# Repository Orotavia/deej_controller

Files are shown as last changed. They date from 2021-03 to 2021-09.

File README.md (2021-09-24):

# deej_controller

Custom controller for use with omriharel's [deej](https://github.com/omriharel/deej) software. Reads four rotary encoders with edge-driven interrupts to increment/decrement volume per channel. Volume data is sent over serial to the FT230X which appears as a serial port on the host PC. 

Known issues:
* FT230X and MCP1700 both output 3.3V onto the same rail. Need to separate to prevent voltage mis-match and resultant backwards current flow. 
* 5.3x10.2 SOIC16W footprints for SN74HC595N shift registers are too wide - Need to switch to SOIC16
* LED Bargraph footprints are too wide - Need to reduce row-to-row spacing, must likely by 2.54mm or some multiple

deej!

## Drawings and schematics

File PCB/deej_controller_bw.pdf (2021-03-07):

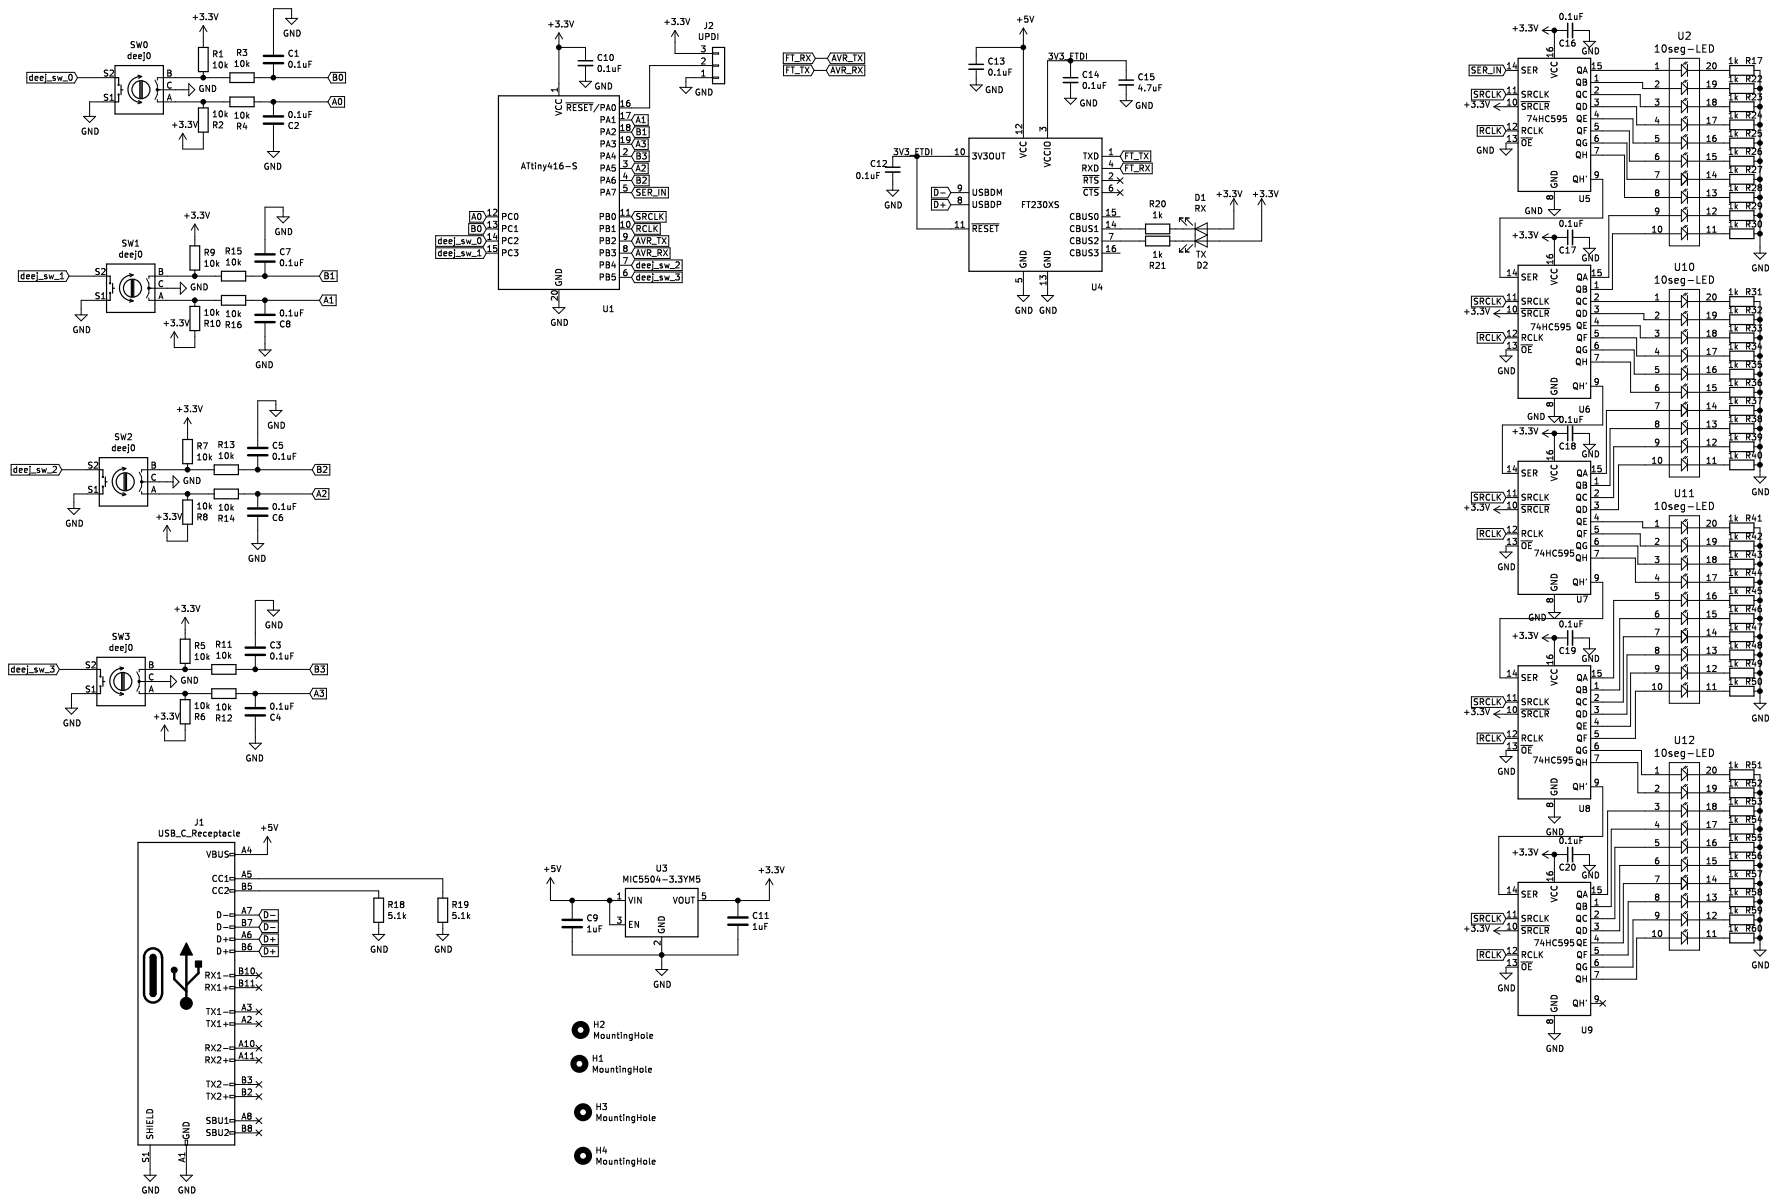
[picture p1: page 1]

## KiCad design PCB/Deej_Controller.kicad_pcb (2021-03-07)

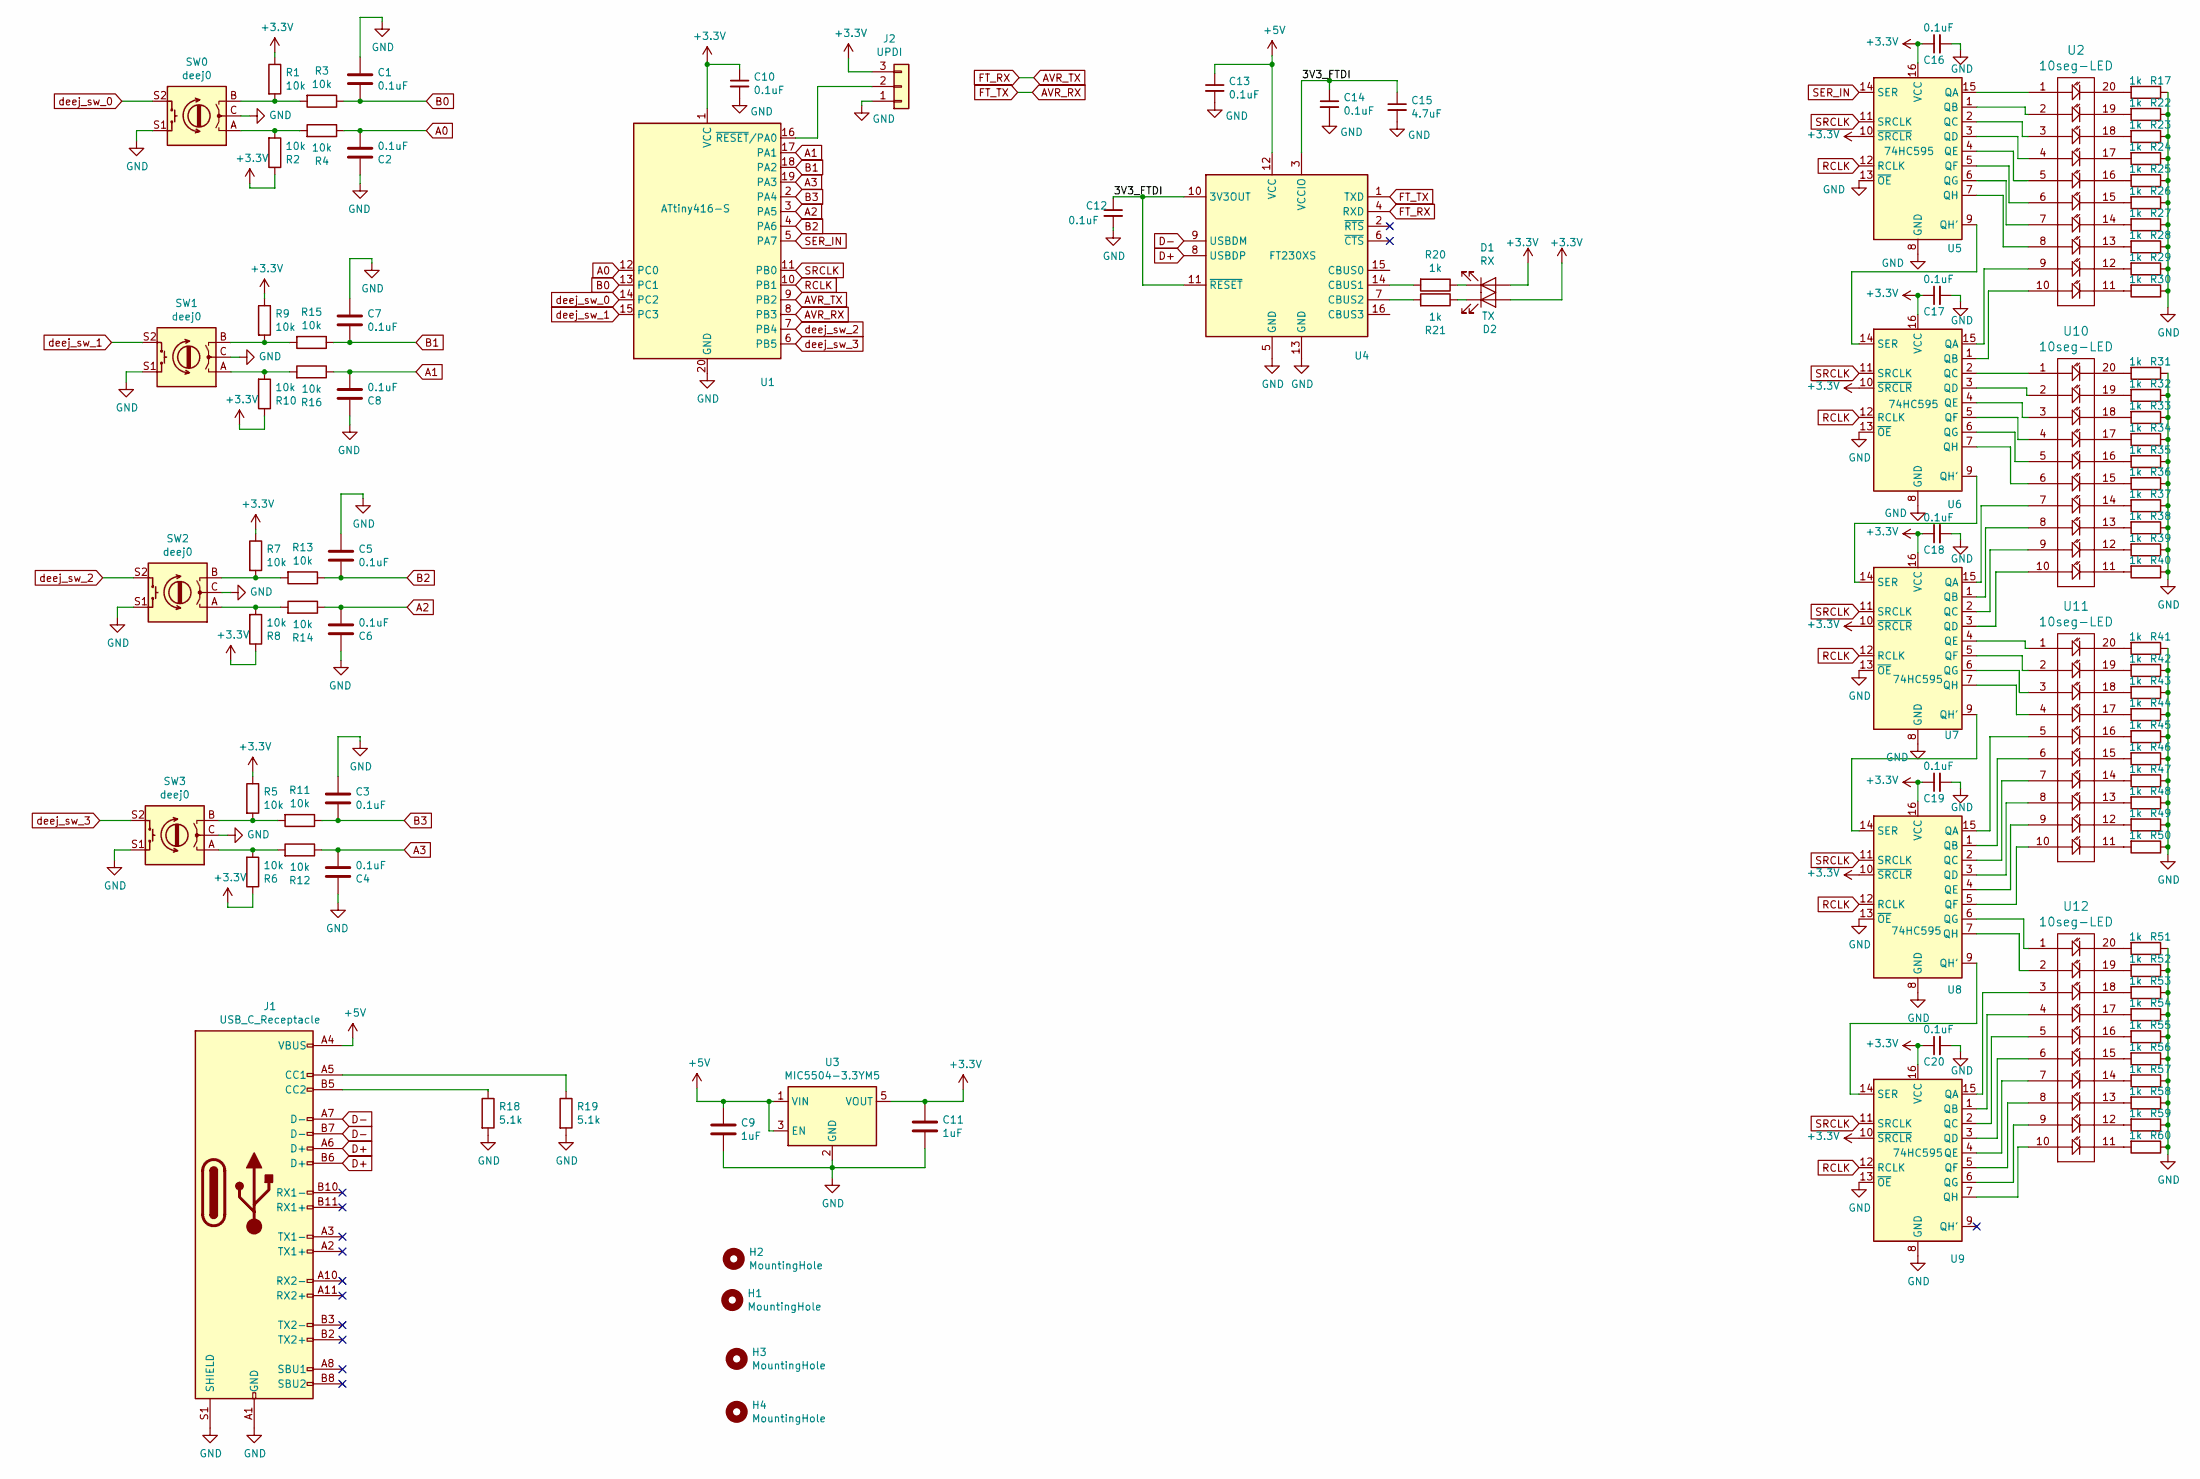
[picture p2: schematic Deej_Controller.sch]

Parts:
C1, C2, C3, C4, C5, C6, C7, C8, C10, C12, C13, C14, C16, C17, C18, C19, C20: 0.1uF; C_0603
C9, C11: 1uF; C_0603
C15: 4.7uF; C_0603
D1: RX; LED_0603
D2: TX; LED_0603
H1, H2, H3, H4: MountingHole; MountingHole_3.2mm_M3_DIN965_Pad
J1: USB_C_Receptacle; USB_C_GCT_ThruHole
J2: UPDI; UPDI_Header_2.54_smd
R1, R2, R3, R4, R5, R6, R7, R8, R9, R10, R11, R12, R13, R14, R15, R16: 10k; R_0603
R17, R20, R21, R22, R23, R24, R25, R26, R27, R28, R29, R30, R31, R32, R33, R34, R35, R36, R37, R38, R39, R40, R41, R42, R43, R44, R45, R46, R47, R48, R49, R50, R51, R52, R53, R54, R55, R56, R57, R58, R59, R60: 1k; R_0603
R18, R19: 5.1k; R_0603
SW0, SW1, SW2, SW3: deej0; PEC11R-Encoder
U1: ATtiny416-S; SOIC-20W_7.5x12.8mm_Pitch1.27mm
U2, U10, U11, U12: 10seg-LED; 10Segment_LED
U3: MIC5504-3.3YM5; SOT-23-5
U4: FT230XS; SSOP-16_3.9x4.9mm_Pitch0.635mm
U5, U6, U7, U8, U9: 74HC595; SOIC-16W_5.3x10.2mm_Pitch1.27mm

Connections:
+5V: C9.1, C13.1, J1.A4 (VBUS), J1.A9 (VBUS), J1.B4 (VBUS), J1.B9 (VBUS), U3.1 (VIN), U3.3 (EN), U4.12 (VCC)
A0: C2.1, R4.1, U1.12 (PC0)
A1: C8.1, R16.1, U1.17 (PA1)
A2: C6.1, R14.1, U1.3 (PA5)
A3: C4.1, R12.1, U1.19 (PA3)
AVR_RX: U1.8 (PB3), U4.1 (TXD)
AVR_TX: U1.9 (PB2), U4.4 (RXD)
B0: C1.1, R3.1, U1.13 (PC1)
B1: C7.1, R15.1, U1.18 (PA2)
B2: C5.1, R13.1, U1.4 (PA6)
B3: C3.1, R11.1, U1.2 (PA4)
D+: J1.A6 (D+), J1.B6 (D+), U4.8 (USBDP)
D-: J1.A7 (D-), J1.B7 (D-), U4.9 (USBDM)
GND: C1.2, C2.2, C3.2, C4.2, C5.2, C6.2, C7.2, C8.2, C9.2, C10.2, C11.2, C12.2, C13.2, C14.2, C15.2, C16.2, C17.2, C18.2, C19.2, C20.2, J1.A1 (GND), J1.A12 (GND), J1.B1 (GND), J1.B12 (GND), J1.S1 (SHIELD), J2.1, R17.1, R18.2, R19.2, R22.1, R23.1, R24.1, R25.1, R26.1, R27.1, R28.1, R29.1, R30.1, R31.1, R32.1, R33.1, R34.1, R35.1, R36.1, R37.1, R38.1, R39.1, R40.1, R41.1, R42.1, R43.1, R44.1, R45.1, R46.1, R47.1, R48.1, R49.1, R50.1, R51.1, R52.1, R53.1, R54.1, R55.1, R56.1, R57.1, R58.1, R59.1, R60.1, SW0.C, SW0.S1, SW1.C, SW1.S1, SW2.C, SW2.S1, SW3.C, SW3.S1, U1.20 (GND), U3.2 (GND), U4.5 (GND), U4.13 (GND), U5.8 (GND), U5.13 (~OE), U6.8 (GND), U6.13 (~OE), U7.8 (GND), U7.13 (~OE), U8.8 (GND), U8.13 (~OE), U9.8 (GND), U9.13 (~OE)
unnamed: D1.1 (K), R20.1
unnamed: D2.1 (K), R21.1
unnamed: J1.A5 (CC1), R19.1
unnamed: J1.B5 (CC2), R18.1
unnamed: J2.2, U1.16 (~RESET~/PA0)
unnamed: R1.2, R3.2, SW0.B
unnamed: R2.2, R4.2, SW0.A
unnamed: R10.2, R16.2, SW1.A
unnamed: R5.2, R11.2, SW3.B
unnamed: R6.2, R12.2, SW3.A
unnamed: R7.2, R13.2, SW2.B
unnamed: R8.2, R14.2, SW2.A
unnamed: R9.2, R15.2, SW1.B
unnamed: R17.2, U2.20
unnamed: R20.2, U4.14 (CBUS1)
unnamed: R21.2, U4.7 (CBUS2)
unnamed: R22.2, U2.19
unnamed: R23.2, U2.18
unnamed: R24.2, U2.17
unnamed: R25.2, U2.16
unnamed: R26.2, U2.15
unnamed: R27.2, U2.14
unnamed: R28.2, U2.13
unnamed: R29.2, U2.12
unnamed: R30.2, U2.11
unnamed: R31.2, U10.20
unnamed: R32.2, U10.19
unnamed: R33.2, U10.18
unnamed: R34.2, U10.17
unnamed: R35.2, U10.16
unnamed: R36.2, U10.15
unnamed: R37.2, U10.14
unnamed: R38.2, U10.13
unnamed: R39.2, U10.12
unnamed: R40.2, U10.11
unnamed: R41.2, U11.20
unnamed: R42.2, U11.19
unnamed: R43.2, U11.18
unnamed: R44.2, U11.17
unnamed: R45.2, U11.16
unnamed: R46.2, U11.15
unnamed: R47.2, U11.14
unnamed: R48.2, U11.13
unnamed: R49.2, U11.12
unnamed: R50.2, U11.11
unnamed: R51.2, U12.20
unnamed: R52.2, U12.19
unnamed: R53.2, U12.18
unnamed: R54.2, U12.17
unnamed: R55.2, U12.16
unnamed: R56.2, U12.15
unnamed: R57.2, U12.14
unnamed: R58.2, U12.13
unnamed: R59.2, U12.12
unnamed: R60.2, U12.11
unnamed: U2.1, U5.15 (QA)
unnamed: U2.2, U5.1 (QB)
unnamed: U2.3, U5.2 (QC)
unnamed: U2.4, U5.3 (QD)
unnamed: U2.5, U5.4 (QE)
unnamed: U2.6, U5.5 (QF)
unnamed: U2.7, U5.6 (QG)
unnamed: U2.8, U5.7 (QH)
unnamed: U2.9, U6.15 (QA)
unnamed: U2.10, U6.1 (QB)
unnamed: U5.9 (QH'), U6.14 (SER)
unnamed: U6.9 (QH'), U7.14 (SER)
unnamed: U7.9 (QH'), U8.14 (SER)
unnamed: U8.9 (QH'), U9.14 (SER)
unnamed: U6.2 (QC), U10.1
unnamed: U6.3 (QD), U10.2
unnamed: U6.4 (QE), U10.3
unnamed: U6.5 (QF), U10.4
unnamed: U6.6 (QG), U10.5
unnamed: U6.7 (QH), U10.6
unnamed: U7.15 (QA), U10.7
unnamed: U7.1 (QB), U10.8
unnamed: U7.2 (QC), U10.9
unnamed: U7.3 (QD), U10.10
unnamed: U7.4 (QE), U11.1
unnamed: U7.5 (QF), U11.2
unnamed: U7.6 (QG), U11.3
unnamed: U7.7 (QH), U11.4
unnamed: U8.15 (QA), U11.5
unnamed: U8.1 (QB), U11.6
unnamed: U8.2 (QC), U11.7
unnamed: U8.3 (QD), U11.8
unnamed: U8.4 (QE), U11.9
unnamed: U8.5 (QF), U11.10
unnamed: U8.6 (QG), U12.1
unnamed: U8.7 (QH), U12.2
unnamed: U9.15 (QA), U12.3
unnamed: U9.1 (QB), U12.4
unnamed: U9.2 (QC), U12.5
unnamed: U9.3 (QD), U12.6
unnamed: U9.4 (QE), U12.7
unnamed: U9.5 (QF), U12.8
unnamed: U9.6 (QG), U12.9
unnamed: U9.7 (QH), U12.10
RCLK: U1.10 (PB1), U5.12 (RCLK), U6.12 (RCLK), U7.12 (RCLK), U8.12 (RCLK), U9.12 (RCLK)
SER_IN: U1.5 (PA7), U5.14 (SER)
SRCLK: U1.11 (PB0), U5.11 (SRCLK), U6.11 (SRCLK), U7.11 (SRCLK), U8.11 (SRCLK), U9.11 (SRCLK)
deej_sw_0: SW0.S2, U1.14 (PC2)
deej_sw_1: SW1.S2, U1.15 (PC3)
deej_sw_2: SW2.S2, U1.7 (PB4)
deej_sw_3: SW3.S2, U1.6 (PB5)

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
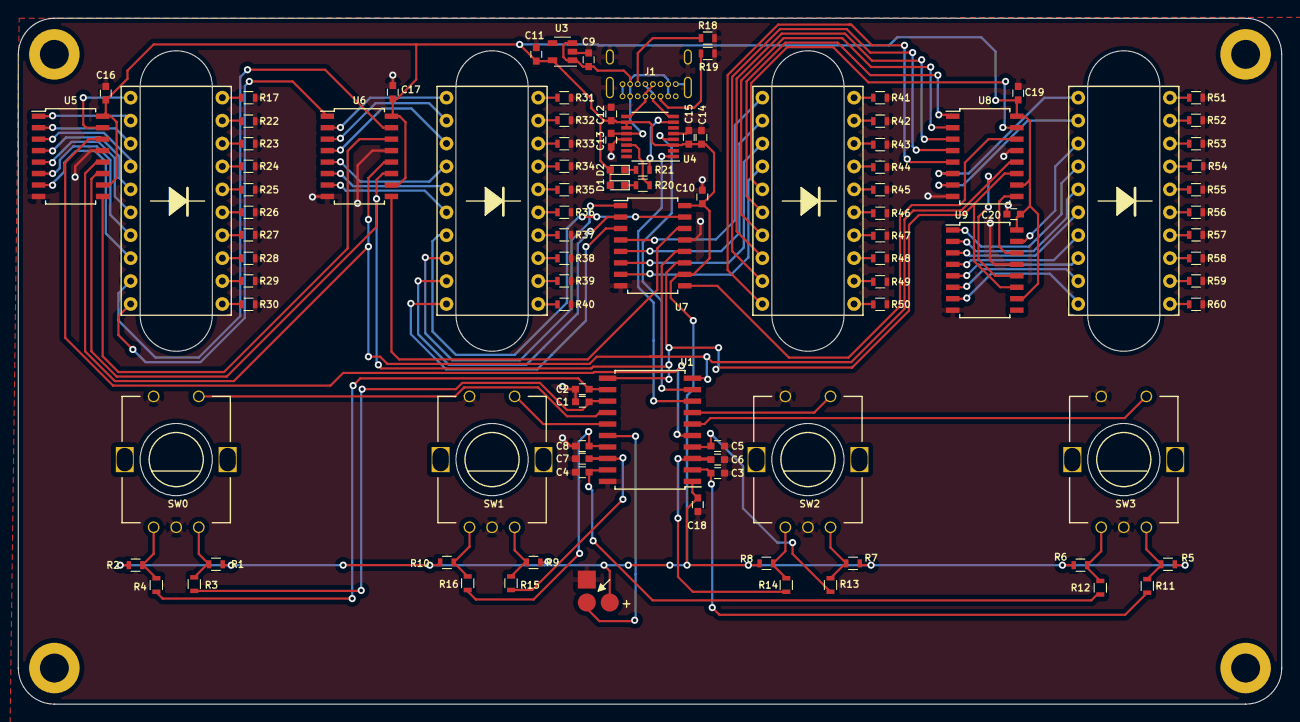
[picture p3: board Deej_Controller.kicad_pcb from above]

Board: 2 copper layers, 140.0 x 76.0 mm, 104 parts (0 on the bottom side), 121 nets.

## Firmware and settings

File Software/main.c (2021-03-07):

/*
 * deej_controller.c
 *
 * Created: 9/27/2020 7:20:21 PM
 * Author : stomp
 */ 

// On Port C
#define EN0_A (1<<0)
#define EN0_B (1<<1)
#define EN0_SW (1<<2)
#define EN1_SW (1<<3)

// On Port B
#define EN2_SW (1<<4)
#define EN3_SW (1<<5)

// On Port A
#define EN1_A (1<<1)
#define EN1_B (1<<2)
#define EN3_A (1<<3)
#define EN3_B (1<<4)
#define EN2_A (1<<5)
#define EN2_B (1<<6)

#define SHIFT_CLK (1<<0)
#define LATCH_CLK (1<<1)
#define SR_DATA (1<<7)

#define mem_clickRate ((uint8_t *)5)
#define mem_saveDelay ((uint8_t *)6)
#define mem_updatePeriod ((uint16_t *)7)
// address 8 not available due to period being 16-bit word

//static const char msg_clickSave[] = "Volume will increment %d per click\n>";

#include <avr/io.h>
#include <avr/interrupt.h>
#include <avr/sleep.h>
#include <stdio.h>
#include <util/delay.h>
#include <string.h>
#include <stdlib.h>
#include <avr/eeprom.h>
#include "usart_lib.h"
//#include "tiny_clk_setup.h"
#include "tiny_rtc.h"

volatile int8_t load_flag[] = {0, 0, 0, 0};
volatile int32_t encoder_accum[] = {0, 0, 0, 0};
volatile uint8_t mute[] = {0xFF, 0xFF, 0xFF, 0xFF};
	
volatile uint8_t chg_flag = 0;


uint8_t enc_inc = 2;
uint8_t save_delay = 10;
uint16_t update_period = 500;

volatile uint8_t rx_index;
volatile uint8_t rx_word;

volatile uint8_t save_flag = 0;

char rx_message[32];
char tx_message[32];
char * arg;
uint8_t argD = 0;

uint32_t parser(char *in_string, uint8_t argc){
	uint8_t parse_index = 0;
	uint8_t match_count = 0;
	char token_buf[6] = "";
	uint32_t token_index = 0;
	
	while(match_count < (argc+1)){
		while((in_string[parse_index++] != ' ') && parse_index < 32);
		if(parse_index < 32)
			match_count++;
	}
	
	while((in_string[parse_index] !=  ' ') && (in_string[parse_index] != '\n') && (in_string[parse_index] != 0)){
		token_buf[token_index++] = in_string[parse_index++];
	}
	token_index = strtol(token_buf, NULL, 10);
	return token_index;
	
}

void updateAllFromMemory(){
	enc_inc = eeprom_read_byte(mem_clickRate);
	save_delay = eeprom_read_byte(mem_saveDelay);
	update_period = eeprom_read_word(mem_updatePeriod);
	for(uint16_t i = 0; i < 4; i++){
		encoder_accum[i] = eeprom_read_byte((uint8_t*)i);
	}
}

void shiftWrite5(uint64_t data){
	for(uint8_t i=0; i<(8*5); i++){
		if(data & 0x01){
			PORTA.OUTSET = SR_DATA;
		} else{
			PORTA.OUTCLR = SR_DATA;
		}
		
		PORTB.OUTSET = SHIFT_CLK;
		_delay_us(10);
		PORTB.OUTCLR = SHIFT_CLK;
		
		data=data>>1;  //Now bring next bit at MSB position
	}
	PORTB.OUTSET = LATCH_CLK;
	_delay_us(10);
	PORTB.OUTCLR = LATCH_CLK;
}

uint64_t percentToLED(uint8_t in){
	switch((in+9)/10){
		case 0:
			return 0x000;
			break;
		case 1:
			return 0x001;
			break;
		case 2:
			return 0x003;
			break;
		case 3:
			return 0x007;
			break;
		case 4:
			return 0x00F;
		case 5:
			return 0x01F;
			break;
		case 6:
			return 0x03F;
			break;
		case 7:
			return 0x07F;
			break;
		case 8:
			return 0x0FF;
			break;
		case 9:
			return 0x1FF;
			break;
		case 10:
			return 0x3FF;
			break;
		default:
			return 0x000;
			break;
	}
		
}

void updateLEDs(){
	uint64_t led_val = (percentToLED(encoder_accum[0]&mute[0]) << 30) | (percentToLED(encoder_accum[1]&mute[1]) << 20) | (percentToLED(encoder_accum[2]&mute[2]) << 10) | (percentToLED(encoder_accum[3]&mute[3]) << 0);
	shiftWrite5( led_val );
}

void startTimerA(uint16_t top){
	TCA0.SINGLE.INTCTRL = TCA_SINGLE_OVF_bm;
	TCA0.SINGLE.PER = (uint32_t)top*(F_CPU/1024)/1000;
	TCA0.SINGLE.CNT = 0;
	TCA0.SINGLE.CTRLA = TCA_SINGLE_ENABLE_bm | TCA_SINGLE_CLKSEL_DIV1024_gc;
}

void stopTimerA(){
	TCA0.SINGLE.CTRLA &= ~TCA_SINGLE_ENABLE_bm;
	TCA0.SINGLE.INTFLAGS = TCA_SINGLE_OVF_bm;	//clear flag
}

int main(void){
	//_delay_ms(1000);
    usart_init(F_CPU, 9600);
	//usart_tx_string("begin\n>");		// REPLACE WITH reads from EEPROM
	
	updateAllFromMemory();

	PORTA.DIRSET = SR_DATA;
	PORTB.DIRSET = SHIFT_CLK | LATCH_CLK;

	PORTA.DIRCLR = EN1_A | EN1_B | EN2_A | EN2_B | EN3_A | EN3_B;
	PORTB.DIRCLR = EN2_SW | EN3_SW;
	PORTC.DIRCLR = EN0_A | EN0_B | EN0_SW | EN1_SW;
	
	PORTA.PIN1CTRL |= PORT_ISC_BOTHEDGES_gc;	//EN1 A
	PORTA.PIN2CTRL |= PORT_ISC_BOTHEDGES_gc;	//EN1 B
	PORTA.PIN3CTRL |= PORT_ISC_BOTHEDGES_gc;	//EN3 A
	PORTA.PIN4CTRL |= PORT_ISC_BOTHEDGES_gc;	//EN3 B
	PORTA.PIN5CTRL |= PORT_ISC_BOTHEDGES_gc;	//EN2 A
	PORTA.PIN6CTRL |= PORT_ISC_BOTHEDGES_gc;	//EN2 B
	
	PORTC.PIN0CTRL |= PORT_ISC_BOTHEDGES_gc;	//EN0 A
	PORTC.PIN1CTRL |= PORT_ISC_BOTHEDGES_gc;	//EN0 B
	
	PORTC.PIN2CTRL |= PORT_ISC_FALLING_gc | PORT_PULLUPEN_bm;	//EN0 SW
	PORTC.PIN3CTRL |= PORT_ISC_FALLING_gc | PORT_PULLUPEN_bm;	//EN1 SW
	PORTB.PIN4CTRL |= PORT_ISC_FALLING_gc | PORT_PULLUPEN_bm;	//EN2 SW
	PORTB.PIN5CTRL |= PORT_ISC_FALLING_gc | PORT_PULLUPEN_bm;	//EN3 SW
	
	
	//for(uint16_t i = 0; i < updateRate; i++){
	for(uint8_t i = 0; i < 10; i++){
		shiftWrite5((((uint64_t)1<<i)<<0) | (((uint64_t)1<<i)<<10) | (((uint64_t)1<<i)<<20) | (((uint64_t)1<<i)<<30));
		_delay_ms(100);
	}
		//sprintf(tx_message, "%d|%d|%d|%d\r\n", (int)(1023*(encoder_accum[0]&mute[0])/100), (int)(1023*(encoder_accum[1]&mute[1])/100), (int)(1023*(encoder_accum[2]&mute[2])/100), (int)(1023*(encoder_accum[3]&mute[3])/100));
		//usart_tx_string(tx_message);
	//}
	updateLEDs();
	
	startTimerA(update_period);

	sei();
	set_sleep_mode(SLEEP_MODE_IDLE);
    while (1){
		
		
		sleep_mode();
		
		// **********************
		// Physical Interaction Response
		// **********************
		if(chg_flag){
			rtc_start(save_delay, RTC_PRESCALER_DIV32768_gc);		// after delay, save to EEPROM. 
			
			for(uint8_t i = 0; i < 4; i++){
				if(encoder_accum[i] > 100){
					encoder_accum[i] = 100;
				} else if(encoder_accum[i] < 0){
					encoder_accum[i] = 0;
				} 
			}
			
			updateLEDs();
			sprintf(tx_message, "%d|%d|%d|%d\r\n", (int)(1023*(encoder_accum[0]&mute[0])/100), (int)(1023*(encoder_accum[1]&mute[1])/100), (int)(1023*(encoder_accum[2]&mute[2])/100), (int)(1023*(encoder_accum[3]&mute[3])/100));
			usart_tx_string(tx_message);
			chg_flag = 0;
		}
		/*for(uint8_t i = 0; i < 4; i++){
			if(chg_flag[i]){
				chg_flag[i] = 0;
				rtc_start(save_delay, RTC_PRESCALER_DIV32768_gc);		// after delay, save to EEPROM. 
													// add 'EN0' bit to the flag, so it saves Encoder 0's value, eg
			
				if(encoder_accum[i] > 100){
					encoder_accum[i] = 100;
				} else if(encoder_accum[i] < 0){
					encoder_accum[i] = 0;
				} else{
					updateLEDs();
					sprintf(tx_message, "%d|%d|%d|%d\r\n", (int)(1023*(encoder_accum[0]&mute[0])/100), (int)(1023*(encoder_accum[1]&mute[1])/100), (int)(1023*(encoder_accum[2]&mute[2])/100), (int)(1023*(encoder_accum[3]&mute[3])/100));
					usart_tx_string(tx_message);
				}
			}
		}*/
		
		// **********************
		// Periodic UART Update
		// **********************
		if(TCA0.SINGLE.INTFLAGS & TCA_SINGLE_OVF_bm){
			TCA0.SINGLE.INTFLAGS = TCA_SINGLE_OVF_bm;	//clear flag
			sprintf(tx_message, "%d|%d|%d|%d\r\n", (int)(1023*(encoder_accum[0]&mute[0])/100), (int)(1023*(encoder_accum[1]&mute[1])/100), (int)(1023*(encoder_accum[2]&mute[2])/100), (int)(1023*(encoder_accum[3]&mute[3])/100));
			usart_tx_string(tx_message);
		}
		
		// **********************
		// Post-Delay EEPROM Save
		// **********************
		if(save_flag & 0x80){
			if(save_flag & (1<<0))
				//usart_tx_string("Saved EN0!\n");	//EEPROM write 0				
				eeprom_write_byte((uint8_t *)0, encoder_accum[0]);
			if(save_flag & (1<<1))
				//usart_tx_string("Saved EN1!\n");	//EEPROM write 1
				eeprom_write_byte((uint8_t *)1, encoder_accum[1]);
			if(save_flag & (1<<2))
				//usart_tx_string("Saved EN2!\n");	//EEPROM write 2
				eeprom_write_byte((uint8_t *)2, encoder_accum[2]);
			if(save_flag & (1<<3))
				//usart_tx_string("Saved EN3!\n");	//EEPROM write 3
				eeprom_write_byte((uint8_t *)3, encoder_accum[3]);
			
			save_flag = 0;
		}
		
		// **********************
		// UART Command Interface
		// **********************
		if(rx_word){
			stopTimerA();
			if(!strcmp(rx_message, "help\n") || !strcmp(rx_message, "?\n") || !strcmp(rx_message, "commands\n")){
				usart_tx_string("setClickRate n\n\tSets the increment/decrement ");
				usart_tx_string("per encoder click, 1-100\n\n");
				
				usart_tx_string("setSaveDelay n\n\tSets the delay in seconds ");
				usart_tx_string("after which I save volumes to EEPROM, 1-255\n\n");
				
				usart_tx_string("setVolume n m\n\tSets the volume of encoder n ");
				usart_tx_string("to the value of m, 0-100\n\n");
				
				usart_tx_string("setUpdateRate n\n\tSets time between volume");
				usart_tx_string("updates in ms, 0-255\n\n");
				
				usart_tx_string("resume\n\tResumes periodic operation\n\n");
				
				sprintf(tx_message, "ClickRate = %d    SaveDelay = %d    Update Period = %d\n>", enc_inc, save_delay, update_period);
				usart_tx_string(tx_message);
				
			} else if(!strncmp(rx_message, "setClickRate ", 13) && rx_index >= 14){
				enc_inc = parser(rx_message, 0);
				eeprom_write_byte(mem_clickRate, enc_inc);
				sprintf(tx_message, "Volume will increment %d per click\n>", enc_inc);
				usart_tx_string(tx_message);
				
			} else if(!strncmp(rx_message, "setSaveDelay ", 13) && rx_index >= 14){
				save_delay = parser(rx_message, 0);
				eeprom_write_byte(mem_saveDelay, save_delay);
				sprintf(tx_message, "Volume will save after %d seconds\n>", save_delay);
				usart_tx_string(tx_message);
				
			} else if(!strncmp(rx_message, "setVolume ", 10) && rx_index >= 13){
				encoder_accum[parser(rx_message, 0)] = parser(rx_message, 1);
				sprintf(tx_message, "Encoder %d volume set to %d\n>", (int)parser(rx_message, 0), (int)parser(rx_message, 1));
				usart_tx_string(tx_message);
				
			} else if(!strncmp(rx_message, "setUpdatePeriod ", 16) && rx_index >= 17){
				update_period = parser(rx_message, 1);
				eeprom_write_word(mem_updatePeriod, update_period);
				sprintf(tx_message, "Volume will send every %d milliseconds\n>", update_period);
				usart_tx_string(tx_message);
			} else if(!strncmp(rx_message, "resume", 6)){
				startTimerA(update_period);
			}
			
			usart_reset_rx();
		}
		
    }
}

ISR(PORTA_PORT_vect){
	
	switch(PORTA.INTFLAGS){
		case(EN1_A):
			if(((PORTA.IN&EN1_A) && !(PORTA.IN&EN1_B)) || (!(PORTA.IN&EN1_A) && (PORTA.IN&EN1_B))){
				encoder_accum[1] += enc_inc;
				chg_flag = 0xFF;
				save_flag |= (1<<1);
			}
			break;
		case(EN1_B):
			if(((PORTA.IN&EN1_A) && !(PORTA.IN&EN1_B)) || (!(PORTA.IN&EN1_A) && (PORTA.IN&EN1_B))){
				encoder_accum[1] -= enc_inc;
				chg_flag = 0xFF;
				save_flag |= (1<<1);
			}
			break;
		
		case(EN2_A):
			if(((PORTA.IN&EN2_A) && !(PORTA.IN&EN2_B)) || (!(PORTA.IN&EN2_A) && (PORTA.IN&EN2_B))){
				encoder_accum[2] += enc_inc;
				chg_flag = 0xFF;
				save_flag |= (1<<2);
			}
			break;
		case(EN2_B):
			if(((PORTA.IN&EN2_A) && !(PORTA.IN&EN2_B)) || (!(PORTA.IN&EN2_A) && (PORTA.IN&EN2_B))){
				encoder_accum[2] -= enc_inc;
				chg_flag = 0xFF;
				save_flag |= (1<<2);
			}
		break;
		
		case(EN3_A):
			if(((PORTA.IN&EN3_A) && !(PORTA.IN&EN3_B)) || (!(PORTA.IN&EN3_A) && (PORTA.IN&EN3_B))){
				encoder_accum[3] += enc_inc;
				chg_flag = 0xFF;
				save_flag |= (1<<3);
			}
			break;
		case(EN3_B):
			if(((PORTA.IN&EN3_A) && !(PORTA.IN&EN3_B)) || (!(PORTA.IN&EN3_A) && (PORTA.IN&EN3_B))){
				encoder_accum[3] -= enc_inc;
				chg_flag = 0xFF;
				save_flag |= (1<<3);
			}
			break;
		
		default:
			break;
	}
	PORTA.INTFLAGS = 0xFF;
}



ISR(PORTB_PORT_vect){
	switch(PORTB.INTFLAGS){
		case(EN2_SW):
			mute[2] ^= 0xFF;
			chg_flag = 0xFF;
			save_flag |= (1<<2);
			_delay_ms(50);
			while(!(PORTB.IN&EN2_SW));
			_delay_ms(50);
			break;
		case(EN3_SW):
			mute[3] ^= 0xFF;
			chg_flag = 0xFF;
			save_flag |= (1<<3);
			_delay_ms(50);
			while(!(PORTB.IN&EN3_SW));
			_delay_ms(50);
			break;
		default:
			break;
	}
	PORTB.INTFLAGS = 0xFF;
}



ISR(PORTC_PORT_vect){
	
	switch(PORTC.INTFLAGS){
		case(EN0_A):
			if(((PORTC.IN&EN0_A) && !(PORTC.IN&EN0_B)) || (!(PORTC.IN&EN0_A) && (PORTC.IN&EN0_B))){
				encoder_accum[0] += enc_inc;
				chg_flag = 0xFF;
				save_flag |= (1<<0);
			}
			break;
			
		case(EN0_B):
			if(((PORTC.IN&EN0_A) && !(PORTC.IN&EN0_B)) || (!(PORTC.IN&EN0_A) && (PORTC.IN&EN0_B))){
				encoder_accum[0] -= enc_inc;
				chg_flag = 0xFF;
				save_flag |= (1<<0);
			}
			break;
				
		case(EN0_SW):
			mute[0] ^= 0xFF;
			chg_flag = 0xFF;
			save_flag |= (1<<0);
			_delay_ms(50);
			while(!(PORTC.IN&EN0_SW));
			_delay_ms(50);
			break;
		case(EN1_SW):
			mute[1] ^= 0xFF;
			chg_flag = 0xFF;
			save_flag |= (1<<1);
			_delay_ms(50);
			while(!(PORTC.IN&EN1_SW));
			_delay_ms(50);
			break;
			
		default:
			break;
	}	
	PORTC.INTFLAGS = 0xFF;
}


ISR(USART0_RXC_vect){
	rx_message[rx_index] = usart_rx();
	if(rx_message[rx_index++] == '\n'){			//terminate word on newline
		rx_word = 0xFF;
	}
}

ISR(RTC_CNT_vect){
	save_flag |= 0x80;		// the 'activate' bit
	rtc_stop();
	RTC_INTFLAGS = (RTC_OVF_bm) | (RTC_CMP_bm);
}

ISR(TCA0_OVF_vect){
	
}

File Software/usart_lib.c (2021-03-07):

#include <avr/io.h>
#include <stdint.h>
#include <string.h>
#include <stdlib.h>

extern uint8_t rx_index = 0x00;
extern uint8_t rx_word = 0x00;
extern volatile char rx_message[50];

void usart_init(uint32_t fclk, uint32_t baud){
	USART0.BAUD = 64UL*fclk / (16UL*baud);		
	PORTB.DIRSET = (1 << 2);	//PB2 as output for UART TX		
	PORTB.DIRCLR = (1 << 3);	//PB1 as input for UART RX		
	USART0.CTRLA = (USART_RXCIE_bm) | (USART_RXSIE_bm);						//interrupts on recieve character and start frame			
	USART0.CTRLB = (USART_RXEN_bm) | (USART_TXEN_bm) | (USART_SFDEN_bm);	//RX, TX, and start frame detect
	//USART0.DBGCTRL = 0x01;
}

void usart_tx(char a){
	while(!(USART0.STATUS & USART_DREIF_bm));	//while data register NOT empty
	USART0.TXDATAL = a;							//write data
	while(!(USART0.STATUS & USART_TXCIF_bm));	//wait for transmit complete
	USART0.STATUS |= (USART_TXCIF_bm);			//clear tx_complete flag
}

void usart_tx_string(char str[]){
	uint8_t i = 0;
	while(str[i] != 0){
		usart_tx(str[i++]);
	}
}

void usart_tx_val(int32_t input, uint8_t base){
	char message[32];
	itoa(input, message, base);
	usart_tx_string(message);
}

char usart_rx(){
	while(!(USART0.STATUS & USART_RXCIF_bm));	//wait for RX flag to go high
	return USART0.RXDATAL;
}

void usart_reset_rx(){
	rx_word = 0;
	rx_index = 0;
	memset(rx_message, 0x00, 32);
}

/*
ISR(USART0_RXC_vect){
	rx_message[rx_index] = usart_rx();
	if(rx_message[rx_index++] == '\n'){			//terminate word on newline
		rx_word = 0xFF;
	}
}*/
